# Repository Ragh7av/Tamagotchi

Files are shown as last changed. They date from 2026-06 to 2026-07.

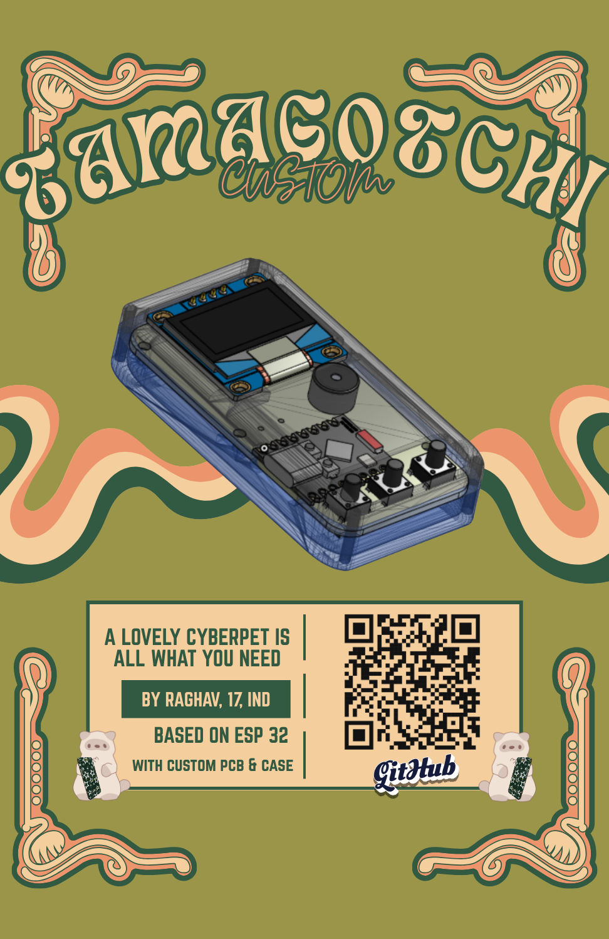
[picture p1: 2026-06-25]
ZINE/Zine.png

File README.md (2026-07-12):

 <h1 align="center">Tamagotchi</h1>


<div align="center">         
<p align="center">
Super smol tamagotchi pet for you!
</p>

<h1 align="center">Overview</h1>
        
<p align="center">
 
 Custom tamagotchi with a super small formfactor and can help you [larp](https://en.wiktionary.org/wiki/LARP) building hardware. Made using the good old ESP32 C3 Supermini, an 0.96 oled panel, three [smol](https://en.wiktionary.org/wiki/smol) tactile switches, buzzer, and a battery [ofc](https://en.wikipedia.org/wiki/OFC) with a custom PCB and a 3D printed case! 

 [Onshape 3D Model link](https://cad.onshape.com/documents/aaa376a98daf92ea29d656f5/w/34884ae89482b25306f22cdd/e/82753004b14a47683b19c43f)

 #  Schematic


# Printed Circuit Board (PCB)





# 3D MODEL OF ASSEMBLY




# ZINE

Zine-Tamagotchi

<h1 align="center">Why did I even build this?</h1>
<p align="center">
 
 to [larp](https://en.wiktionary.org/wiki/LARP) as a super smol cyberpet is cool [asf](https://en.wikipedia.org/wiki/Autism_Science_Foundation). 
 
 </p>

<h1 align="center">The Features</h1>
</div>

**Feeding:** Fills the hunger meter (much like a crunchy kfc) with sound effects

**Playing:** Yooo... Pauses the normal world to launch the falling-item arcade game. Catching items makes the pet superrrr happy but sadlyy acts as a 20% battery tax on its energy.

**Sleeping:** Dims the screen into a snoozee/ sleeping mode, locking the controls until its energy battery safely recharges back to 100% and get's into full powerr.

# The Components Used

1. ESP32 C3 supermini.
2. 0.96-inch OLED Display (SSD1306)
3. smol Buzzer.
4. 6mm x 6mm x 8mm Tactile Switches (x3).
5. Battery
7. Custom designes PCB.
8. Custom 3D Printed Case.

# How to Build it?
## 1. Project Files and Parts
Download the necessary files from this repository:
* Gerbers: For ordering the custom PCB.
* 3D Prints: For printing the outer case.
* Firmware: For the Arduino source code.

Now collect all the hardware components. You will need an ESP32-C3 Supermini, a 0.96-inch I2C OLED display, three 6mm tactile switches, a buzzer and a battery cell.
## 2. Hardware Assembly

To assemble the hardware follow these steps:
1. Solder the ESP32-C3 Supermini onto the designated footprint on your PCB.
2. Next solder the three switches into positions SW4, SW5 and SW6.
3. Then solder the OLED display into the U2 slot.
4. After that solder the buzzer to the BZ1 pads.
5. Solder the battery wires to the BT1 power pads. It is very important to check the schematic to ensure the positive and negative match exactly to prevent shorting out the ESP32-C3 Supermini board.
6. Finally, Place the PCB in the 3D printed bottom case and screw it to the case.

## 3. Software Environment Setup

To set up the software environment follow these steps:

1. Install the Arduino IDE on your computer.
3. Go to File then Preferences. Add the official ESP32 library URL to the Additional Boards Manager URLs box.
5. Open Tools, Board then Boards Manager, search for ESP32 by Expressif and click install.
6. Go back to Tools, Board, then ESP32 Arduino and select ESP32 C3 Dev Module.

## 4. Library Installation and Flashing

To install the library and flash the firmware follow these steps:

1. Go to Sketch Include Library then Manage Libraries.
2. Search for Adafruit SSD1306. Click install. Select "Install All" to include the required Adafruit GFX dependency.
3. Open your project firmware file in the Arduino IDE.
4. Connect the ESP32-C3 Supermini device to your computer using a data cable.
5. Select the devices connection port, under Tools, Port.
6. Click the Upload button. The OLED screen will boot up with the system text soon as the terminal finishes writing the code to the ESP32-C3 Supermini.
   
<h1>Inspirations & Credits</h1> 
Huge thanks to the <strong>Fallout Hack Club Tamagotchi guide</strong> for the base inspiration and logic outline.

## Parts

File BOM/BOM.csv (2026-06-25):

Name | Link | Qty | Price in INR
ESP 32 SUPERMINI | quartz | 1 | 275
6*6*8MM TACTILE SWITCHES | robu | 3 | 5
BUZZER | https://robu.in/product/hc9042-05-cldz-electromagnetic-passive-integrated-buzzer-5v9x4-2mmimpedance42ω/ | 1 | 16
500 MaH LiPo battery | https://robu.in/product/500mah-pcm-protected-micro-li-po-battery-2/ | 1 | 235
0.96 inch OLED SSID1306 | https://robu.in/product/0-96-inch-ssd1306-white-oled-display-module/ | 1 | 209
CUSTOM PCB | https://zbotic.in/pcb-manufacturing/ | 1 | 950
CUSTOM 3D PRINTED CASE | https://dwartindustries.com | 1 | 350
Total |  |  | 2040

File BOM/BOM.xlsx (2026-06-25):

Name | Link | Qty | Price in INR
ESP 32 SUPERMINI | quartz (https://quartzcomponents.com/products/esp32-c3-super-mini-development-board-with-soldered-headers-hw-466ab) | 1 | 275
6*6*8MM TACTILE SWITCHES | robu (https://robu.in/product/6x6x8mm-tactile-push-button-switch-pack-of-20/?gad_source=1&gad_campaignid=17427802703) | 3 | 5
BUZZER | https://robu.in/product/hc9042-05-cldz-electromagnetic-passive-integrated-buzzer-5v9x4-2mmimpedance42ω/ | 1 | 16
500 MaH LiPo battery | https://robu.in/product/500mah-pcm-protected-micro-li-po-battery-2/ | 1 | 235
0.96 inch OLED SSID1306 | https://robu.in/product/0-96-inch-ssd1306-white-oled-display-module/ | 1 | 209
CUSTOM PCB | https://zbotic.in/pcb-manufacturing/ | 1 | 950
CUSTOM 3D PRINTED CASE | https://dwartindustries.com | 1 | 350
Total |  |  | 2040

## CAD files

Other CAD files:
CAD/Tamagotchi_assembly_with_case.step
CAD/tamagotchi_complete_case.stl
CAD/Tamagotchi_component_assembly.step
CAD/Tamagotchi_case.step
CAD/Tamagotchi_case_bottom.stl
CAD/Tamagotchi_case_top.stl
CAD/Tamagotchi_component_assembly.stl

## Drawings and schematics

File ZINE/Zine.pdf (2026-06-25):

# CCUUSSTTOOMM

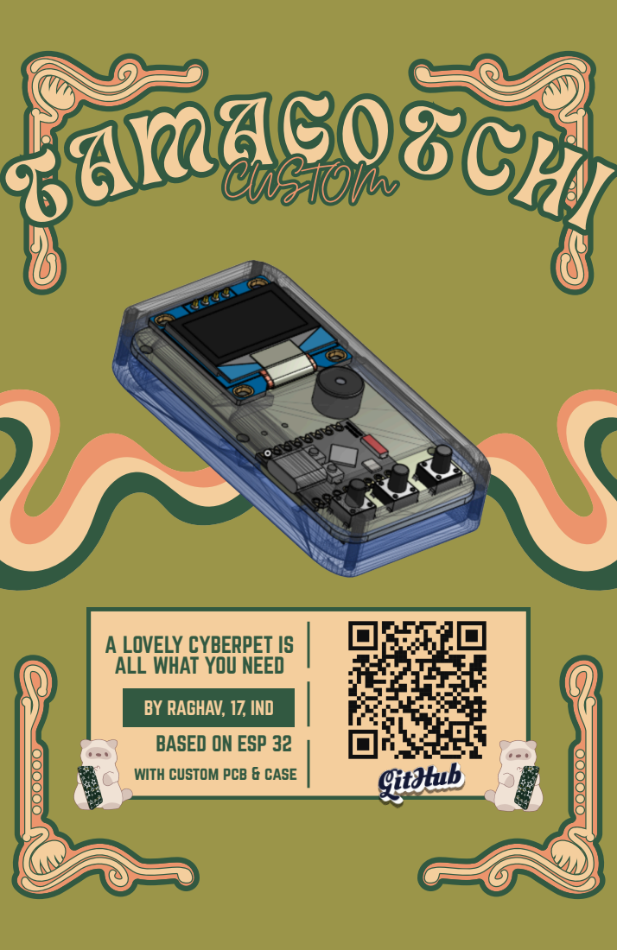
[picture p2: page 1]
TAMAGOTCHI AGOTCHI

A LOVELY CYBERPET IS
ALL WHAT YOU NEED

BY RAGHAV, 17, IND
BASED ON ESP 32
with custom pcb & case

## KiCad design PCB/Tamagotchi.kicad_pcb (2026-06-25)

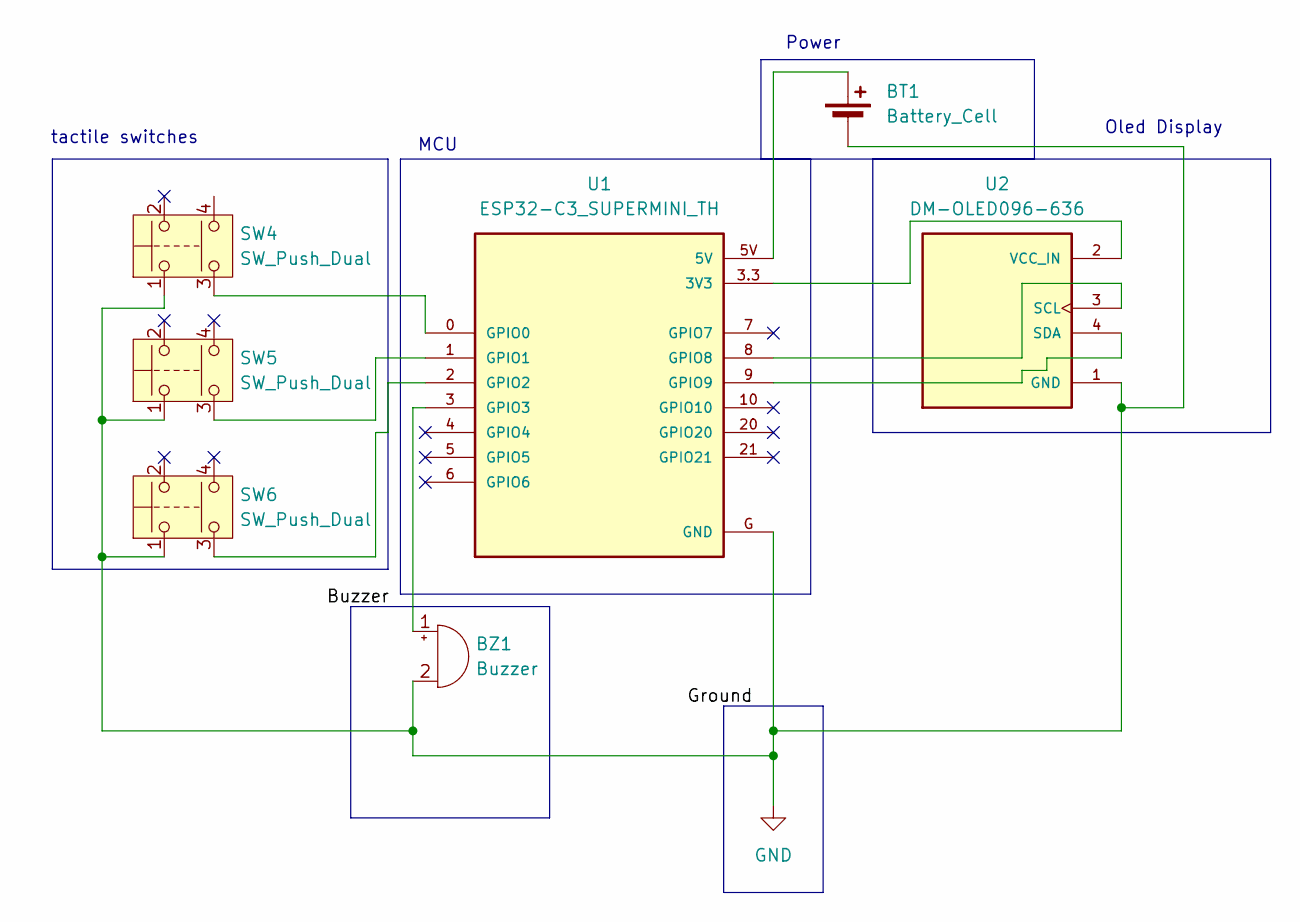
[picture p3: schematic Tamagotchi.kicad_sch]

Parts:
BT1: Battery_Cell; TE_282837-2
BZ1: Buzzer; BUZ-TH_BD9.6-P5.00-D0.6-FD_XHXDZ-TMB9650-5V
SW4, SW5, SW6: SW_Push_Dual; 430182043816
U1: ESP32-C3_SUPERMINI_TH; MODULE_ESP32-C3_SUPERMINI_TH
U2: DM-OLED096-636; 128x64OLED SSD1306; PARTREV 2018-09-10

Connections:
GND: BT1.2 (-), BZ1.2 (-), SW4.1, SW5.1, SW6.1, U1.G (GND), U2.1 (GND)
unnamed: BT1.1 (+), U1.5V
unnamed: BZ1.1 (+), U1.3 (GPIO3)
unnamed: U1.3.3 (3V3), U2.2 (VCC_IN)
unnamed: SW4.3, U1.0 (GPIO0)
unnamed: SW5.3, U1.1 (GPIO1)
unnamed: SW6.3, U1.2 (GPIO2)
unnamed: U1.8 (GPIO8), U2.3 (SCL)
unnamed: U1.9 (GPIO9), U2.4 (SDA)

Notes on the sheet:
MCU
tactile switches
Power
Oled Display

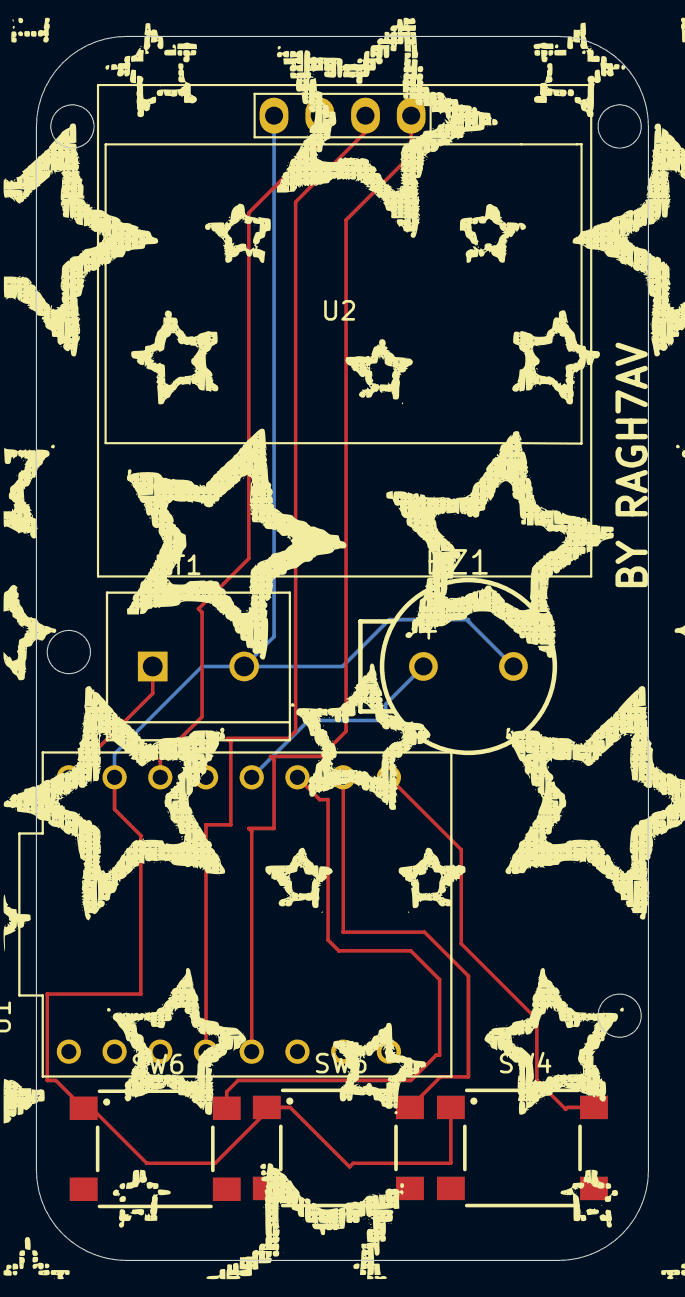
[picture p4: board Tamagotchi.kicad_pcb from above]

Board: 2 copper layers, 34.0 x 68.0 mm, 7 parts (0 on the bottom side), 9 nets.

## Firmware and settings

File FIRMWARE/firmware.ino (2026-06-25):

#include <Wire.h>
#include <Adafruit_GFX.h>
#include <Adafruit_SSD1306.h>

#define SCREEN_WIDTH 128
#define SCREEN_HEIGHT 64
#define OLED_RESET    -1
#define SCREEN_ADDRESS 0x3C

// Pin layout directly mapping image_2026-06-25_181045654.png
#define PIN_BTN_LEFT   0  // SW4
#define PIN_BTN_SELECT 1  // SW5
#define PIN_BTN_RIGHT  2  // SW6
#define PIN_BUZZER     3  // BZ1
#define I2C_SDA        9  // U2 SDA
#define I2C_SCL        8  // U2 SCL

// Core Stats
int hunger = 60;       
int happiness = 50;    
int energy = 100;      // New Energy Stat (0-100)

// State Machine
int selectedMenu = 0;  // 0 = FEED, 1 = PLAY, 2 = SLEEP
bool showStatus = false;
bool isSleeping = false;
bool inGame = false;

// Mini-Game Variables
int paddleX = 54;
int itemX = 30;
int itemY = 12;
int gameScore = 0;
int itemsDropped = 0;

unsigned long lastStatTick = 0;
const unsigned long TICK_INTERVAL = 6000; // Stat updates every 6 seconds

Adafruit_SSD1306 display(SCREEN_WIDTH, SCREEN_HEIGHT, &Wire, OLED_RESET);

void playBeep(int frequency, int duration) {
  long delayVal = 1000000 / frequency / 2;
  long numCycles = (long)frequency * duration / 1000;
  for (long i = 0; i < numCycles; i++) {
    digitalWrite(PIN_BUZZER, HIGH);
    delayMicroseconds(delayVal);
    digitalWrite(PIN_BUZZER, LOW);
    delayMicroseconds(delayVal);
  }
}

void setup() {
  pinMode(PIN_BTN_LEFT, INPUT_PULLUP);
  pinMode(PIN_BTN_SELECT, INPUT_PULLUP);
  pinMode(PIN_BTN_RIGHT, INPUT_PULLUP);
  pinMode(PIN_BUZZER, OUTPUT);
  digitalWrite(PIN_BUZZER, LOW);

  Wire.begin(I2C_SDA, I2C_SCL);
  display.begin(SSD1306_SWITCHCAPVCC, SCREEN_ADDRESS);
  
  display.clearDisplay();
  display.setTextSize(1);
  display.setTextColor(SSD1306_WHITE);
  display.setCursor(35, 28);
  display.print("PET OS v2.0");
  display.display();
  delay(1000);
  
  lastStatTick = millis();
}

void loop() {
  // --- 1. Passive Background Stat Management ---
  if (millis() - lastStatTick >= TICK_INTERVAL) {
    lastStatTick = millis();
    
    if (isSleeping) {
      energy += 15;
      if (energy >= 100) {
        energy = 100;
        isSleeping = false; // Automatically wakes up fully charged
        playBeep(1500, 400);
      }
    } else {
      if (hunger > 0) hunger -= 3;
      if (happiness > 0) happiness -= 3;
      if (energy > 0) energy -= 2; // Slow active drain
    }
  }

  // --- 2. Handle Inputs & States ---
  if (inGame) {
    runMiniGameLoop();
  } else if (isSleeping) {
    // Pressing any button wakes the pet early
    if (digitalRead(PIN_BTN_LEFT) == LOW || digitalRead(PIN_BTN_SELECT) == LOW || digitalRead(PIN_BTN_RIGHT) == LOW) {
      isSleeping = false;
      playBeep(1000, 100);
      delay(300);
    }
    drawSleepScreen();
  } else {
    handleStandardInput();
    
    display.clearDisplay();
    if (showStatus) {
      drawStatusScreen();
    } else {
      drawMainScreen();
    }
    display.display();
  }
  
  delay(30); // Global frame limiter
}

// --- Standard UI Input Controller ---
void handleStandardInput() {
  if (digitalRead(PIN_BTN_LEFT) == LOW) {
    selectedMenu = (selectedMenu + 1) % 3; // Loop between 0, 1, 2
    playBeep(1800, 30);
    delay(200); 
  }

  if (digitalRead(PIN_BTN_RIGHT) == LOW) {
    showStatus = !showStatus; 
    playBeep(1400, 40);
    delay(200);
  }

  if (digitalRead(PIN_BTN_SELECT) == LOW) {
    delay(200);
    if (selectedMenu == 0) { // FEED
      hunger = min(hunger + 20, 100);
      playBeep(900, 80); delay(40); playBeep(700, 80);
    } 
    else if (selectedMenu == 1) { // PLAY
      if (energy >= 20) {
        // Init the Mini-game state
        inGame = true;
        gameScore = 0;
        itemsDropped = 0;
        paddleX = 54;
        itemY = 12;
        itemX = random(10, 110);
        playBeep(1200, 100);
      } else {
        // Too tired warning!
        playBeep(300, 300); 
      }
    } 
    else if (selectedMenu == 2) { // SLEEP
      isSleeping = true;
      showStatus = false;
      playBeep(600, 200); delay(50); playBeep(400, 300);
    }
  }
}

// --- Arcade Mini-Game Implementation ---
void runMiniGameLoop() {
  // Input tracking directly inside the game
  if (digitalRead(PIN_BTN_LEFT) == LOW && paddleX > 0) {
    paddleX -= 5;
  }
  if (digitalRead(PIN_BTN_RIGHT) == LOW && paddleX < 112) {
    paddleX += 5;
  }

  // Drop object physics
  itemY += 2;

  // Collision handling (Paddle sits at Y=56)
  if (itemY >= 54) {
    if (itemX >= paddleX && itemX <= (paddleX + 16)) {
      gameScore++;
      playBeep(2200, 50); // High pitch catch indicator
    } else {
      playBeep(400, 80);  // Low pitch miss indicator
    }
    
    // Spawn next object
    itemY = 12;
    itemX = random(5, 120);
    itemsDropped++;
  }

  // Check End Game Condition (After 5 drops)
  if (itemsDropped >= 5) {
    inGame = false;
    energy = max(energy - 20, 0); // Discharge tax for playing
    happiness = min(happiness + (gameScore * 12), 100); // Reward calculations
    
    // Victory fanfare
    playBeep(1500, 80); delay(50);
    playBeep(2000, 150);
    return;
  }

  // Render Mini Game Screen
  display.clearDisplay();
  display.setTextSize(1);
  display.setCursor(0, 0);
  display.print("Score:"); display.print(gameScore);
  display.setCursor(85, 0);
  display.print("Drop:"); display.print(itemsDropped + 1);
  display.drawLine(0, 10, 128, 10, SSD1306_WHITE);

  // Draw Catch Basket Paddle
  display.fillRect(paddleX, 56, 16, 4, SSD1306_WHITE);
  // Draw Falling Fruit/Object
  display.fillCircle(itemX, itemY, 3, SSD1306_WHITE);
  display.display();
}

// --- UI Display Render Panels ---
void drawMainScreen() {
  // Menu Options Rendering
  display.drawRect(2, 2, 38, 13, SSD1306_WHITE);
  display.drawRect(44, 2, 38, 13, SSD1306_WHITE);
  display.drawRect(86, 2, 40, 13, SSD1306_WHITE);
  
  if (selectedMenu == 0) display.fillRect(2, 2, 38, 13, SSD1306_INVERSE);
  if (selectedMenu == 1) display.fillRect(44, 2, 38, 13, SSD1306_INVERSE);
  if (selectedMenu == 2) display.fillRect(86, 2, 40, 13, SSD1306_INVERSE);

  display.setCursor(8, 5);   display.print("FEED");
  display.setCursor(52, 5);  display.print("PLAY");
  display.setCursor(92, 5);  display.print("SLEEP");

  int bounce = (millis() % 800 < 400) ? 0 : 2;
  display.drawRoundRect(48, 25 + bounce, 32, 26, 6, SSD1306_WHITE); // Body

  if (energy < 20) {
    // Exhausted/Dying Expression
    display.setCursor(55, 32 + bounce); display.print("=");
    display.setCursor(67, 32 + bounce); display.print("=");
    display.drawLine(59, 44 + bounce, 67, 44 + bounce, SSD1306_WHITE);
  } else {
    // Normal Face
    display.fillRect(55, 34 + bounce, 3, 3, SSD1306_WHITE);
    display.fillRect(69, 34 + bounce, 3, 3, SSD1306_WHITE);
    display.drawPixel(61, 42 + bounce, SSD1306_WHITE);
    display.drawPixel(65, 42 + bounce, SSD1306_WHITE);
  }
}

void drawSleepScreen() {
  display.clearDisplay();
  int pulse = (millis() % 2000 < 1000);
  
  // Snoozing animations
  display.setCursor(85, 20 - (pulse * 3)); display.print(pulse ? "Zzz" : "zZz");
  
  // Closed eyes pet body representation
  display.drawRoundRect(48, 30, 32, 26, 6, SSD1306_WHITE);
  display.drawLine(54, 39, 58, 39, SSD1306_WHITE); // Closed Left Eye
  display.drawLine(68, 39, 72, 39, SSD1306_WHITE); // Closed Right Eye
  
  display.setCursor(20, 3);
  display.print("Recharging energy...");
  display.display();
}

void drawStatusScreen() {
  display.setCursor(32, 2);
  display.print("PET VITALS");
  display.drawLine(0, 12, 128, 12, SSD1306_WHITE);

  // Hunger Meter
  display.setCursor(2, 18);  display.print("HUNGER");
  display.drawRect(50, 18, 70, 7, SSD1306_WHITE);
  display.fillRect(52, 20, (hunger * 66) / 100, 3, SSD1306_WHITE);

  // Happiness Meter
  display.setCursor(2, 32);  display.print("HAPPY");
  display.drawRect(50, 32, 70, 7, SSD1306_WHITE);
  display.fillRect(52, 34, (happiness * 66) / 100, 3, SSD1306_WHITE);

  // Energy Discharge Meter
  display.setCursor(2, 46);  display.print("ENERGY");
  display.drawRect(50, 46, 70, 7, SSD1306_WHITE);
  display.fillRect(52, 48, (energy * 66) / 100, 3, SSD1306_WHITE);
}

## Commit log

2026-06-20 Create idk cad
2026-06-20 Create BOM
2026-06-25 Configure Git LFS for STEP, STP, and STL files
2026-06-25 Add Tamagotchi project files
    [.stl, Assembly_tamagotchi.stl, Switch_cap.stl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]
